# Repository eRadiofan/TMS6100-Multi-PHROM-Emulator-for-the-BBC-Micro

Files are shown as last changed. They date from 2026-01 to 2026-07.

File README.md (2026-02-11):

# TMS6100 milti-PHROM

This project contains the PCB design and firmware for a TMS6100 emulator, accommodating the following PHROM images:

* Acorn PHROMA (News presenter Kenneth Kendall's voice, Acorn specific format), bank 15
* VM61002 - the PHROM fitted to Acorn computer speech kits sold in the USA (American male voice, indexed phrases), bank 0
* VM10004 - military radio phrases (American male voice, non-indexed phrases), bank 2
* VM71003 - talking clock (American female voice, indexed phrases), bank 4
* Star Wars arcade game prases - from firmware version 1.1 onwards, courtesy of [nmikstas on github](https://nmikstas.github.io/portfolio/swAudio/swAudio.html), who provided [a full dissassembly of the speech ROM](https://github.com/nmikstas/star-wars-arcade-audio/blob/master/Star_Wars_Sound_ROM.asm). Presented on bank 10.

There is also a build option in Firmware/Common/Inc/ROMdata.h to make the following selection:

* Acorn PHROMA (News presenter Kenneth Kendall's voice, Acorn specific format), bank 15
* CD2325a - TI-99/4A PHROM part 1, bank 0
* CD2326a - TI-99/4A PHROM part 2, bank 1
* VM71003 - talking clock (American female voice, indexed phrases), bank 4

Uncomment `#define PHROMS_TI99` and re-build the project. It is provided for experimentation, but the TI-99 phrases were intended for the TMS5200 and don't sound quite right on the TMS5220. To use this emulator in an actual TI-99 speech synthesizer module, pin 13 (CS) must be connected to ground (0V). Schematics for the module show this pin as being connected to +5V.

Content of the PHROMs are documented in the source files located in Firmware/Common/Src/ROMdata_*

The PCB has the footprint of a DIP-28 and is intended to be plugged into the IC98 socket on the BBC Micro model A/B motherboard.

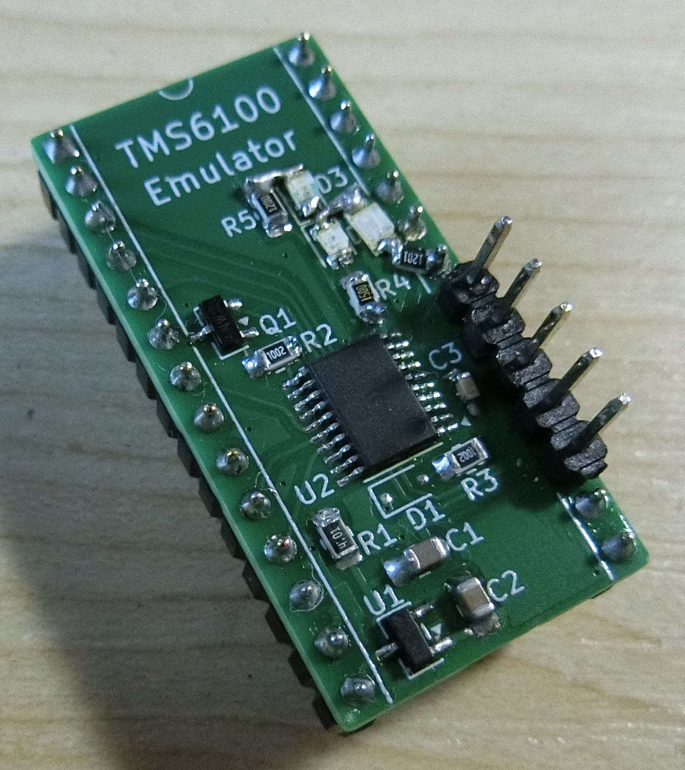
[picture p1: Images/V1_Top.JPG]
PCB constructed


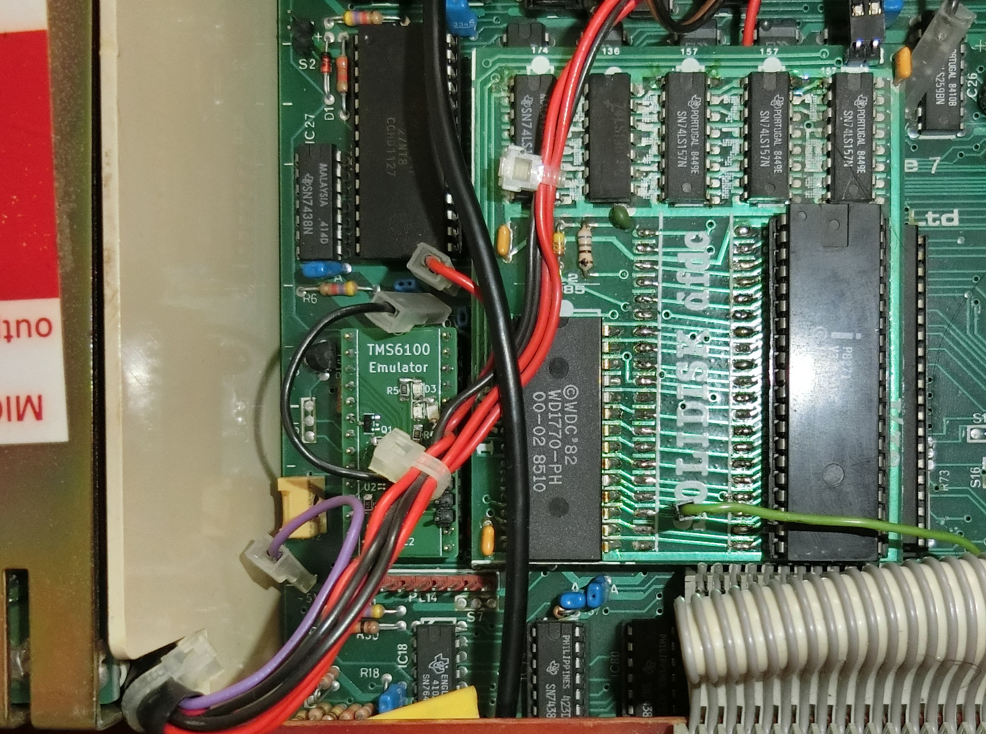
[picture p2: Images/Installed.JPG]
PCB installed into computer


It is a fully-featured implementation, providing indirect addressing and compatibility with other PHROMs connected to the same bus, provided they don't operate in the same address space (check the PHROM bank numbers).

The project is subdivided into multiple sections, stored in the following folders:

* PCB - The Kicad project for the PCB
* Firmware - The STM32CubeIDE project providing the firmware
* Scripts - Utilities for converting data
* BASIC2 - BBC BASIC programs for testing the multi-PHROM
* Images - Photos of the constructed PCB and installation

Each of these sections has their own README, providing more information.

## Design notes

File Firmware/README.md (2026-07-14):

# Firmware

These are STM32CubeIDE version 2.x projects.

There are currently three projects defined, one for the STM32G031F8P6, one for the STM32G051F8P6 and most recently, one for the STM32C051F8P6. Code common to all projects is located in the Common folder.

Use File -> Import -> Import STM32 project -> STM32CubeMX project and choose the project suitable for your MCU.

The first 3 emulators produced were STM32G051F8P6 because that is what I had spare in my parts drawer. The next 30 produced were STM32G031F8P6 because they were the cheapest option at the time. Currently the STM32C051F8P6 seems to be more available and cost effective. Check with your supplier.

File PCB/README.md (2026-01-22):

# PCB

This PCB was designed using Kicad v9.06.

The STM32G051F8P6 MCU is well suited to this project, having 5V tolerant IO, 64K of flash storage and capable of running at 64MHz. STM32G031F8P6 and STM32C051F8P6 should work also.

The PCB has a placeholder for JLCPCB order number, select the correct options when ordering.

Folder AD2_Tests contains Digilent Waveforms workspace configurations for Analog Discovery 2 that were used to test basic read functionality before putting it into the micro.

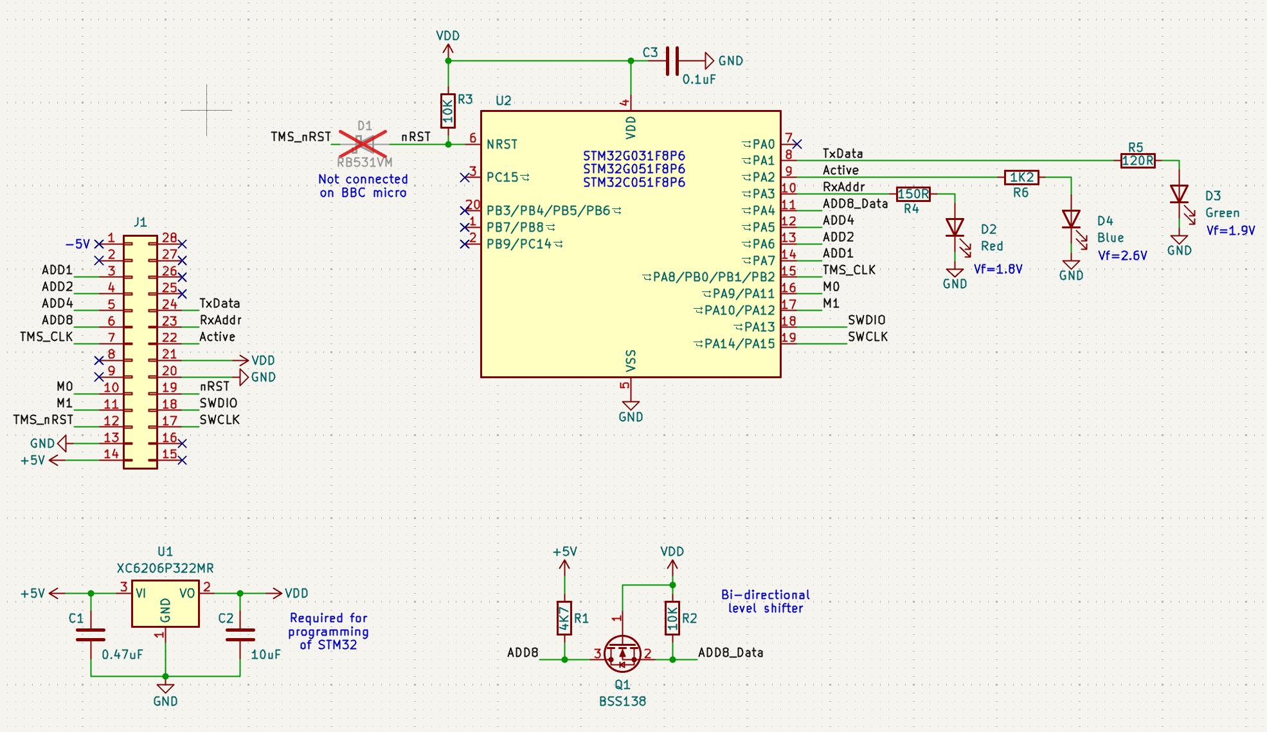
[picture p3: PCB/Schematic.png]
Schematic


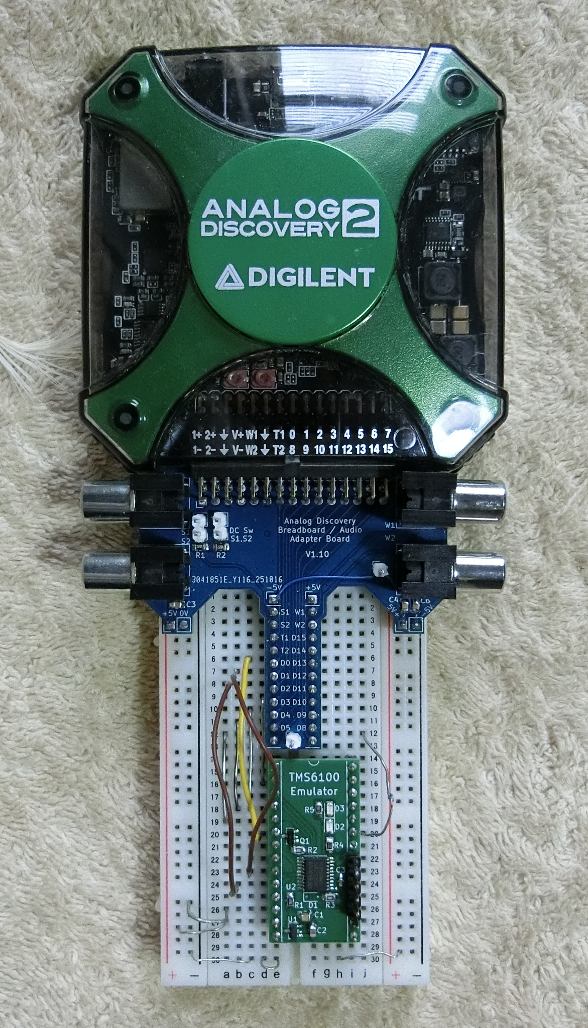
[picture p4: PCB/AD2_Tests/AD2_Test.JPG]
AD2 test setup


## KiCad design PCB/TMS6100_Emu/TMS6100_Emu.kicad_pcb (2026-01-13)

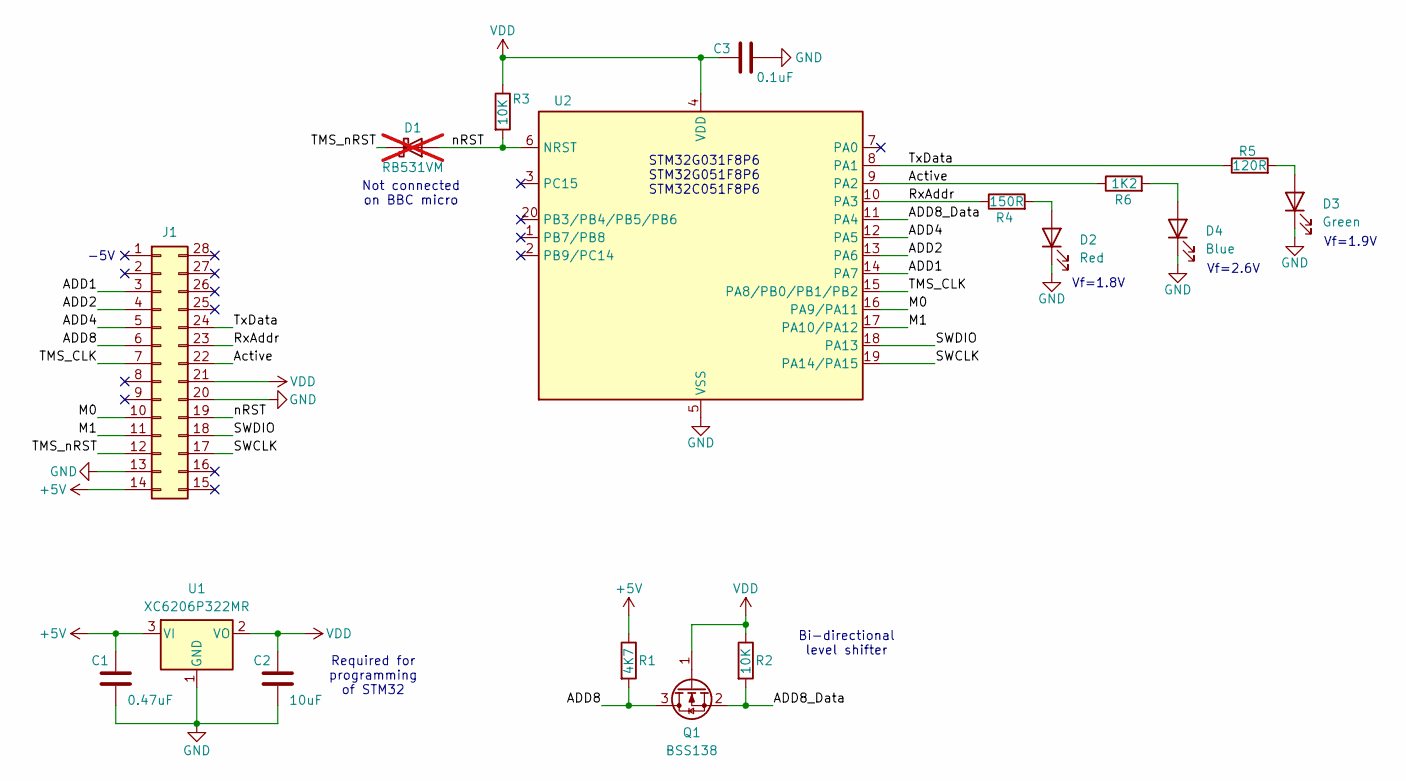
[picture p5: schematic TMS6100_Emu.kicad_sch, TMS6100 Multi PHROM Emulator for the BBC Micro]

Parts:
C1: 0.47uF; C_0805_2012Metric_Pad1.18x1.45mm_HandSolder
C2: 10uF; C_0805_2012Metric_Pad1.18x1.45mm_HandSolder
C3: 0.1uF; C_0603_1608Metric_Pad1.08x0.95mm_HandSolder
D1: RB531VM; D_SOD-323F; not fitted
D2: Red; LED_0805_2012Metric
D3: Green; LED_0805_2012Metric
D4: Blue; LED_0805_2012Metric
J1: Conn_02x14_Counter_Clockwise; DIP-28_W15.24mm_Socket
Q1: BSS138; SOT-23
R1: 4K7; R_0805_2012Metric_Pad1.20x1.40mm_HandSolder
R2, R3: 10K; R_0805_2012Metric_Pad1.20x1.40mm_HandSolder
R4: 150R; R_0805_2012Metric_Pad1.20x1.40mm_HandSolder
R5: 120R; R_0805_2012Metric_Pad1.20x1.40mm_HandSolder
R6: 1K2; R_0805_2012Metric_Pad1.20x1.40mm_HandSolder
U1: XC6206P322MR; SOT-23-3
U2: STM32G051F8P6; TSSOP-20_4.4x6.5mm_P0.65mm

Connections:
+5V: C1.1, J1.14, R1.1, U1.3 (VI)
/ADD1: J1.3, U2.14 (PA7)
/ADD2: J1.4, U2.13 (PA6)
/ADD4: J1.5, U2.12 (PA5)
/ADD8: J1.6, Q1.3 (D), R1.2
/ADD8_Data: Q1.2 (S), R2.2, U2.11 (PA4)
/Active: J1.22, R6.1, U2.9 (PA2)
/M0: J1.10, U2.16 (PA9/PA11)
/M1: J1.11, U2.17 (PA10/PA12)
/RxAddr: J1.23, R4.1, U2.10 (PA3)
/SWCLK: J1.17, U2.19 (PA14/PA15)
/SWDIO: J1.18, U2.18 (PA13)
/TMS_CLK: J1.7, U2.15 (PA8/PB0/PB1/PB2)
/TMS_nRST: D1.1 (K), J1.12
/TxData: J1.24, R5.1, U2.8 (PA1)
/nRST: D1.2 (A), J1.19, R3.2, U2.6 (NRST)
GND: C1.2, C2.2, C3.2, D2.1 (K), D3.1 (K), D4.1 (K), J1.13, J1.20, U1.1 (GND), U2.5 (VSS)
unnamed: D2.2 (A), R4.2
unnamed: D3.2 (A), R5.2
unnamed: D4.2 (A), R6.2
VDD: C2.1, C3.1, J1.21, Q1.1 (G), R2.1, R3.1, U1.2 (VO), U2.4 (VDD)

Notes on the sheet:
Vf=1.9V
STM32G031F8P6 STM32G051F8P6 STM32C051F8P6
Not connected on BBC micro
-5V
Vf=2.6V
Required for programming of STM32
Bi-directional level shifter
Vf=1.8V

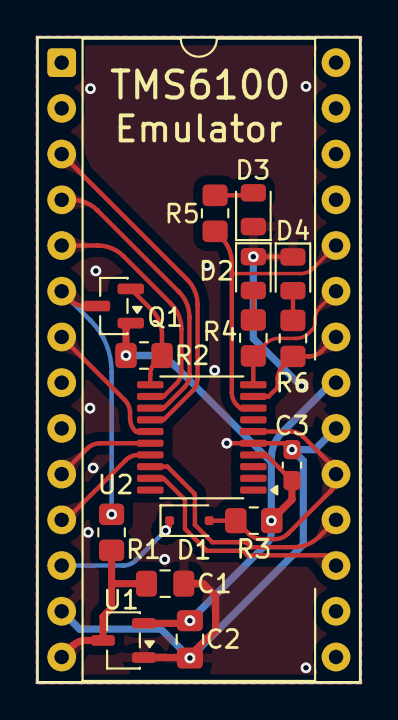
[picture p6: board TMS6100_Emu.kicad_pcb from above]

Board: 2 copper layers, 18.0 x 35.9 mm, 17 parts (0 on the bottom side), 21 nets.

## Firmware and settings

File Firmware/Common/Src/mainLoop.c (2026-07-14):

/*
 * mainLoop.c
 *
 *  Created: Jan 2026
 *   Author: Radiofan
 */
#include "main.h"
#include "SysClock.h"
#include "GPIO.h"
#include "ROMdata.h"

// Pin 15 on the STM32C051F8 is different, cannot use EXTI2, use EXTI8 instead
#ifdef STM32C051xx

// Inactivity timeout = 236ms approx.
#define TIMEOUT 900000UL

static inline void clock_irq_off(void) {
  uint32_t tmp, position = 8;
  // Clear EXTI line configuration
  EXTI->IMR1 &= ~(TMS_CLK_Pin);

  // Clear Falling edge configuration
  EXTI->FTSR1 &= ~(TMS_CLK_Pin);

  // Disable the External Interrupt
  tmp = (0x0FUL) << (8U * (position & 0x03U));
  EXTI->EXTICR[position >> 2U] &= ~tmp;
}

static inline void clock_irq_on(void) {
  uint32_t tmp, position = 8;
  // Enable the External Interrupt
  tmp = EXTI->EXTICR[position >> 2U];
  tmp |= (GPIO_GET_INDEX(TMS_CLK_GPIO_Port) << ((position & 0x03U) * EXTI_EXTICR1_EXTI1_Pos));
  EXTI->EXTICR[position >> 2U] = tmp;

  // Set EXTI line configuration
  EXTI->IMR1 |= TMS_CLK_Pin;

  // Set Falling edge configuration
  EXTI->FTSR1 |= TMS_CLK_Pin;

  // Clear the interrupt
  __HAL_GPIO_EXTI_CLEAR_FALLING_IT(TMS_CLK_Pin);
}

#else

#define TIMEOUT 1200000UL

static inline void clock_irq_off(void) {
  HAL_NVIC_DisableIRQ(EXTI2_3_IRQn);
}
static inline void clock_irq_on(void) {
  HAL_NVIC_EnableIRQ(EXTI2_3_IRQn);
}
#endif


static uint32_t inactive_count = 0;

/* All of the IO functionality is handled by interrupts.
 * This function initialises the MCU and it's peripherals,
 * then looks for idle periods (most of the time) so that
 * it can put the MCU to sleep, thereby saving some leccy.
 */

int main(void) {
  // Reset of all peripherals, Initialises the Flash interface and the Systick.
  HAL_Init();
  // Configure the system clock (48MHz or 64MHz)
  SysClock_Config();
  // Initialise the IO pins
  GPIO_Init();
  // We don't use the HAL timers and we don't want unnecessary interrupts to cause jitter
  HAL_SuspendTick();
  // Blue activity LED on
  GPIO_SetPin(GPIOA, TP1_Pin);

  while (1) {
    if (active) {
      inactive_count = 0;
      active = 0;
    } else
      inactive_count++;
    if (inactive_count > TIMEOUT) {
      // Blue activity LED off
      GPIO_ClrPin(GPIOA, TP1_Pin);
      // Turn off clock interrupts
      clock_irq_off();
      // Check again, just in case a command has just come in
      if (!active) {
        // Go to power saving mode (6.4mA->1.6mA)
        HAL_PWR_EnterSLEEPMode(PWR_MAINREGULATOR_ON, PWR_SLEEPENTRY_WFI);
      }
      // Clock interrupts back on
      clock_irq_on();
      // Blue activity LED on, activates before the end of 1 clock cycle after WFI
      GPIO_SetPin(GPIOA, TP1_Pin);
      // Just in case
      inactive_count = 0;
    }
  }
}

void Error_Handler(void) {
  __disable_irq();
  GPIO_ClrPin(GPIOA, TP1_Pin);
  GPIO_SetPin(GPIOA, LED_Red_Pin);
  GPIO_SetPin(GPIOA, LED_Green_Pin);
  while (1) {
  }
}

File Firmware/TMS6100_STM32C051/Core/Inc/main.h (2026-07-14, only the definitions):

#define LED_Green_Pin GPIO_PIN_1
#define LED_Green_GPIO_Port GPIOA
#define TP1_Pin GPIO_PIN_2
#define TP1_GPIO_Port GPIOA
#define LED_Red_Pin GPIO_PIN_3
#define LED_Red_GPIO_Port GPIOA
#define ADD8_Data_Pin GPIO_PIN_4
#define ADD8_Data_GPIO_Port GPIOA
#define ADD4_Pin GPIO_PIN_5
#define ADD4_GPIO_Port GPIOA
#define ADD2_Pin GPIO_PIN_6
#define ADD2_GPIO_Port GPIOA
#define ADD1_Pin GPIO_PIN_7
#define ADD1_GPIO_Port GPIOA
#define TMS_CLK_Pin GPIO_PIN_8
#define TMS_CLK_GPIO_Port GPIOA
#define TMS_CLK_EXTI_IRQn EXTI4_15_IRQn
#define M0_Pin GPIO_PIN_11
#define M0_GPIO_Port GPIOA
#define M0_EXTI_IRQn EXTI4_15_IRQn
#define M1_Pin GPIO_PIN_12
#define M1_GPIO_Port GPIOA
#define M1_EXTI_IRQn EXTI4_15_IRQn
#define SYS_SWDIO_Pin GPIO_PIN_13
#define SYS_SWDIO_GPIO_Port GPIOA
#define SYS_SWCLK_Pin GPIO_PIN_14
#define SYS_SWCLK_GPIO_Port GPIOA

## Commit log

2026-01-13 Initial commit, content merged from other repositories
    [TMS6100_Emu.kicad_pcb, TMS6100_Emu.kicad_sch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]
2026-01-14 Added initial READMEs and photos of V1 PCB
2026-01-14 Added schematic to README
2026-01-16 Added STM32G031 project and searated out the common code
2026-01-27 Minor fix to Basic program, adjust blue LED resistor value
    [TMS6100_Emu.kicad_sch]
2026-01-30 Fix another bugette in the BASIC program
    [SPHRASE.bas]
2026-02-11 BASIC: improve gap beween phrases, TI99 PHROM b-tree index now decoded, updated READMEs and a small optimisation switching ADD8.
2026-03-01 StarWars fits into TI99 build opt, fixed TI99 PB, better frame debug
    [ROMdata.c, SPHRASE.bas]
2026-07-14 Added firmware spport for STM32C051F8P6

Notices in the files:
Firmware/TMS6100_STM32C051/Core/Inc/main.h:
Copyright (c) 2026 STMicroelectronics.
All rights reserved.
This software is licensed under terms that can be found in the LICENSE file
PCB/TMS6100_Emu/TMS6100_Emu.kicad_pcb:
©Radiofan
